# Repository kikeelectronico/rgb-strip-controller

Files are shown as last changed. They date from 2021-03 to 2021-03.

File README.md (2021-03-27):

View this project on [CADLAB.io](https://cadlab.io/project/24089). 

# RGB Strip controller


***

<br /><span xmlns:dct="http://purl.org/dc/terms/" property="dct:title">RGB strip controller</span> by <span xmlns:cc="http://creativecommons.org/ns#" property="cc:attributionName">Enrique Gómez</span> licensed by <a rel="license" href="http://creativecommons.org/licenses/by-sa/4.0/">Creative Commons Attribution-ShareAlike 4.0 International License</a>.<br /><br />

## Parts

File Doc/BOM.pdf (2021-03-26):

## RGB strip - Rev. 1,0 - Mouser

## Página 1

# RGB strip – Bill of Materials

Rev.: 1,0 | Made By: Enrique Gómez | Verify By: | Date: 03/09/19
Item Designator | Description | Ordering code | Suplier | Manufacturer | Footprint Qty. | Ordering code 2 | Suplier 2 | Value
1 | Q1,Q2,Q3,Q4 | N-channel MOSFET 771-PMV20XNEAR | Mouser | Nexperia | SOT-23 | 4 | PMV20XNEAR | Nexperia
2 | U1 | Linear regulator | 863-MC33275DT-3.3RKG | Mouser | ON Semicon | TO-252-2 | 1 | MC33275DT-3.3RKG | ON Semicon
3 | J1 | Power Jack | 992-CON-SOCJ-2155 | Mouser | Gravitech | 5,5/2,1 mm | 1 | CON-SOCJ-2155 | Gravitech
4 | C1,C2 | | 791-0603X334K250CT | Mouser | Walsin Tech Corp | 0603 | 2 | 0603X334K250CT
5 | R1,R2,R3 | Resistor 10k | 667-ERJ-PB3B1002V | Mouser | Panasonic | 0603 | 1 | ERJPB3B1002V | Panasonic
6 | SW1 | Push button | 688-SKQYAF | Mouser | ALPS | 6,10/3,7 mm | 1 | SKQYAFE010 | ALPS
7 | D2 | Bicolor led | 604-APHB1608QBDCGKC | Mouser | Kingbright | 0603 | 1 | APHB1608QBDCGKC | Kingbright
8 | R5 | Resistor 15 ohm | 667-ERJ-3GEYJ150V | Mouser | Panasonic | 603 | 1 | ERJ-3GEYJ150V | Panasonic
9 | R4 | Resistor 60,4 ohm 667-ERJ-3EKF60R4V | Mouser | Panasonic | 0603 | 1 | ERJ-3EKF60R4V | Panasonic
10 | U2 | ESP8266 | C82891 | LCSC | Ai-Thinker | Module | 1 | ESP-12F(ESP8266MOD) Ai-Thinker
11 | J2 | Header strip | | | | 01x04
12

### Notas:

Multilayer ceramic
capacitor

Walsin Tech
Corp

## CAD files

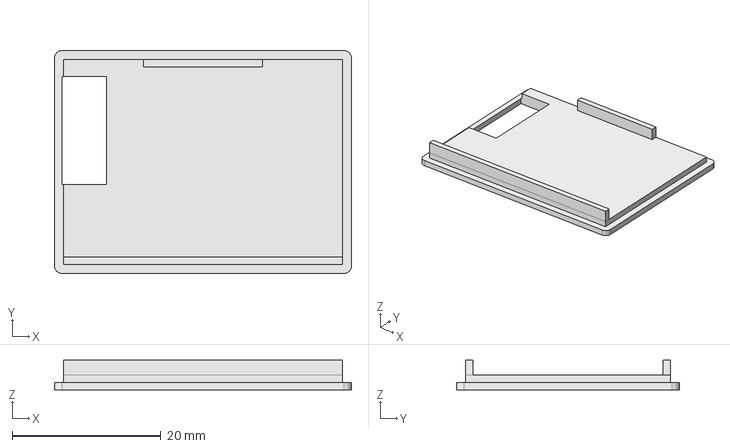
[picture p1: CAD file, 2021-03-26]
enclosure/cover.FCStd
40.0 x 30.0 x 4.00 mm

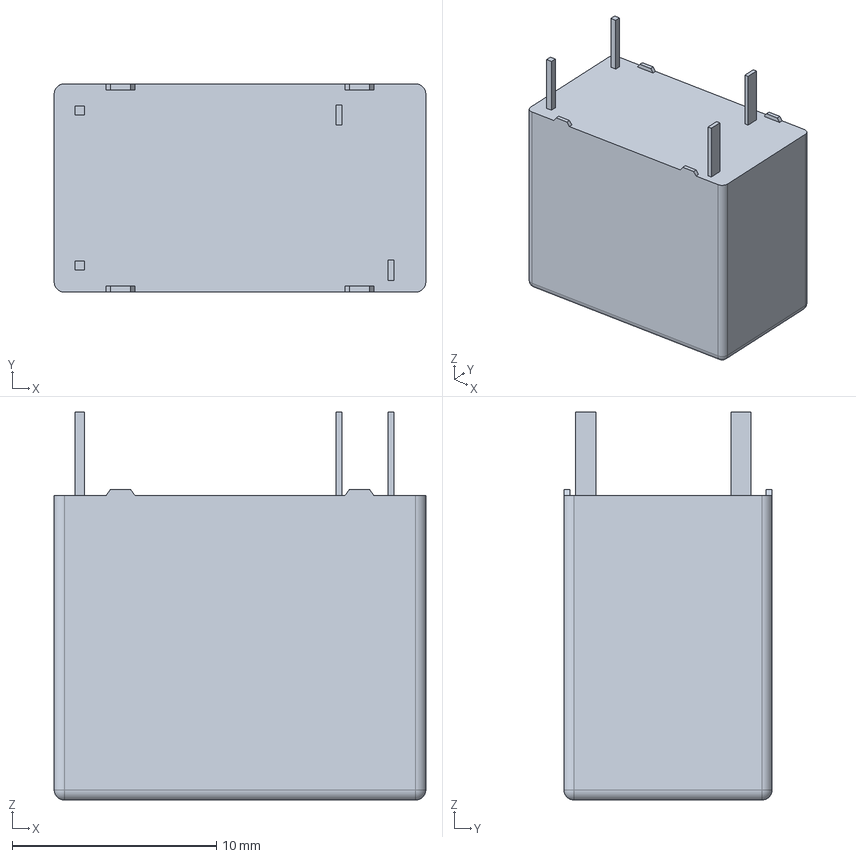
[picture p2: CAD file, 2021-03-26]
Kicad/RGB_strip/3dpackages/c-1461492-2-d4-3d.stp
18.2 x 10.2 x 19.0 mm

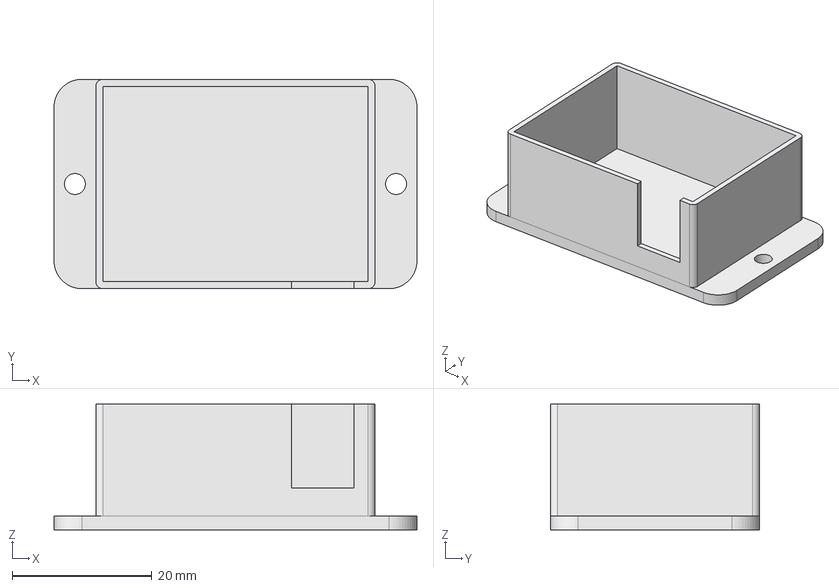
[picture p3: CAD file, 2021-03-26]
enclosure/box.FCStd
52.0 x 30.0 x 18.0 mm

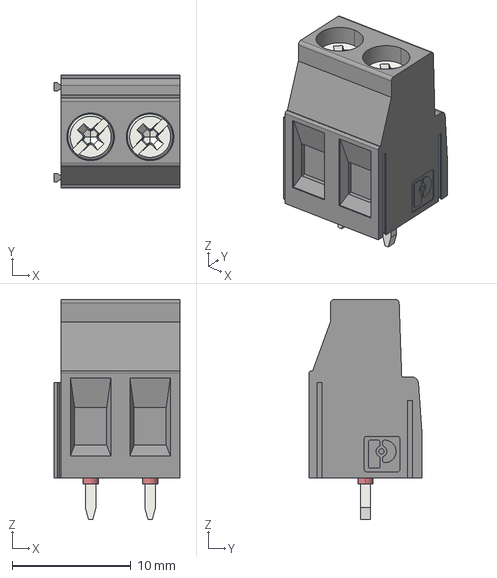
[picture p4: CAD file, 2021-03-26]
Kicad/RGB_strip/3dpackages/pxc_1985920_00_MKDSN-2-5-2-HT-BK_3D.stp
10.6 x 9.50 x 18.5 mm
Bohrloch x 2
mkdsn_2.5-2-ht_bk

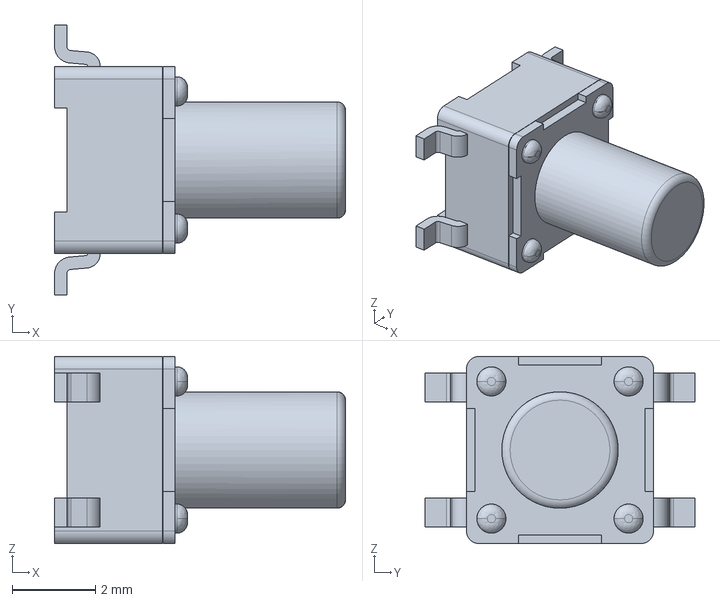
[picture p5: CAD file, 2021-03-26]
Kicad/RGB_strip/3dpackages/PTS647SN70SMTR2LFS.stp
7.00 x 6.50 x 4.50 mm

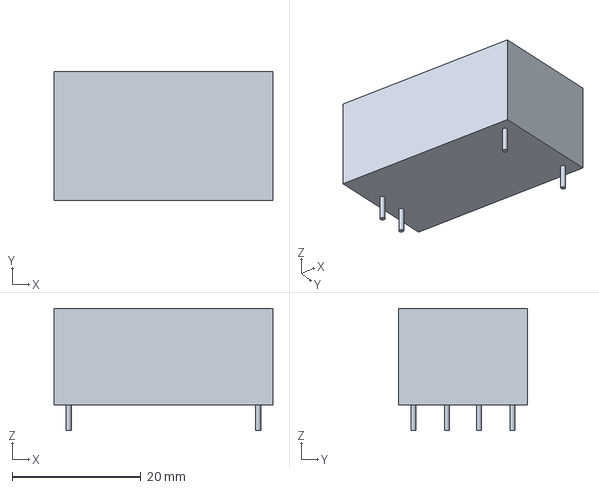
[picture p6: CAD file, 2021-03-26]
Kicad/RGB_strip/3dpackages/AC-DC_HLK-PM01.fcstd
34.0 x 20.0 x 19.0 mm

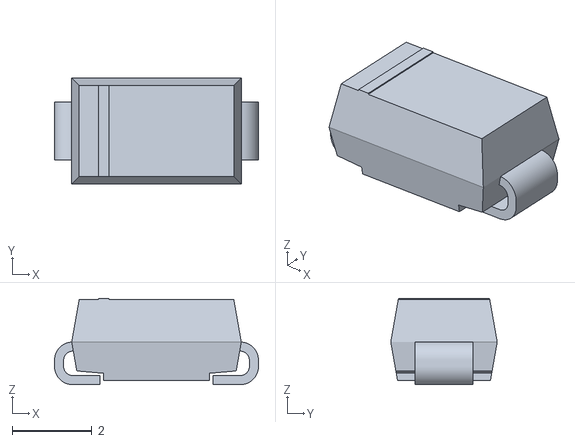
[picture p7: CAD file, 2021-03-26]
Kicad/RGB_strip/3dpackages/AB2_DO-214AC_WINGS3D.stl
5.11 x 2.66 x 2.16

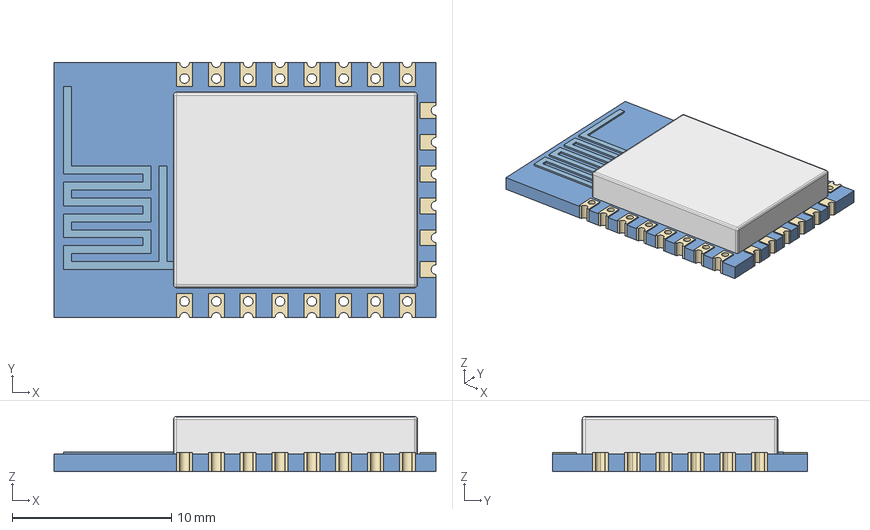
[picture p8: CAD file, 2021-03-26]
Kicad/RGB_strip/3dpackages/ESP8266.fcstd
24.0 x 16.0 x 3.48 mm

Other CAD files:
Kicad/RGB_strip/3dpackages/ESP8266-12E.stp
enclosure/box.stl
enclosure/cover.stl

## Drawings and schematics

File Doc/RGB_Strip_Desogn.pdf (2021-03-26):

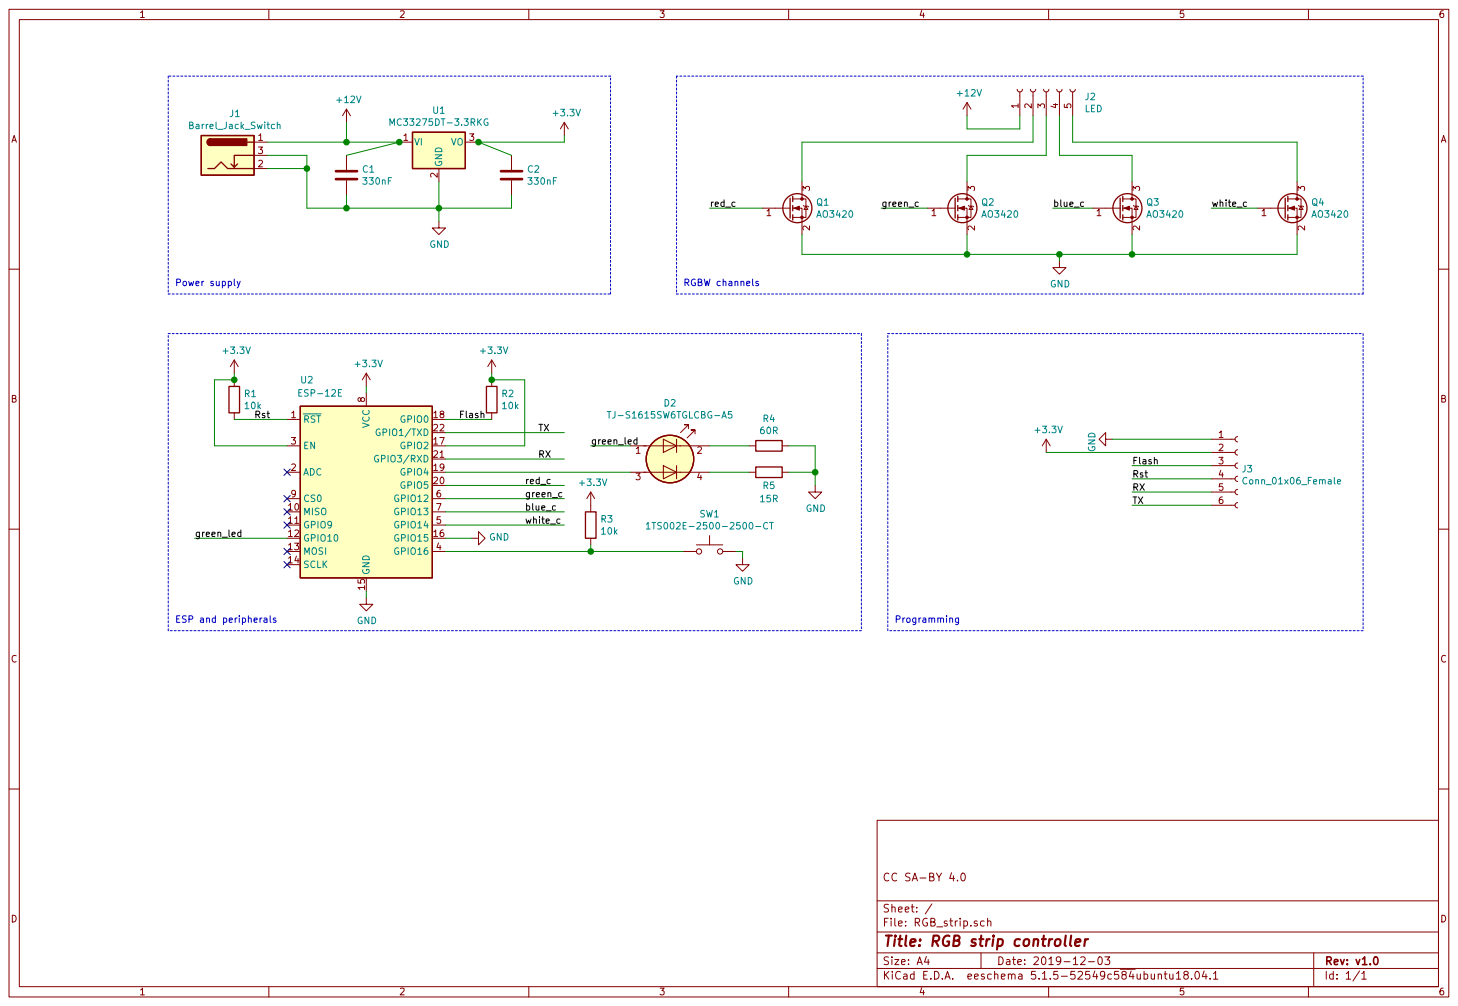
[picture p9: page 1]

2 3 Q4AO3420 RST 1 MISO 10 GPIO9 11 GPIO10 12 MOSI 13 SCLK 14 GND 15 GPIO15 16 GPIO2 17 GPIO0 18 GPIO4 19 ADC 2 GPIO5 20 GPIO3/RXD 21 GPIO1/TXD 22 EN 3 GPIO16 4 GPIO14 5 GPIO12 6 GPIO13 7 VCC

File: RGB_strip.sch Sheet: / CC SA-BY 4.0 R3

Id: 1/1 Title: RGB strip controller

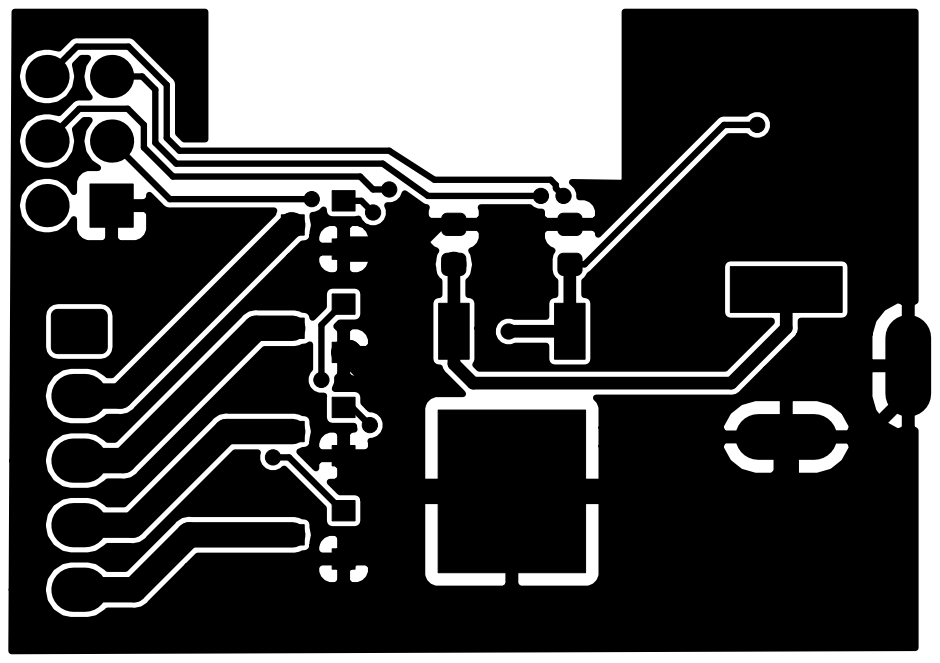
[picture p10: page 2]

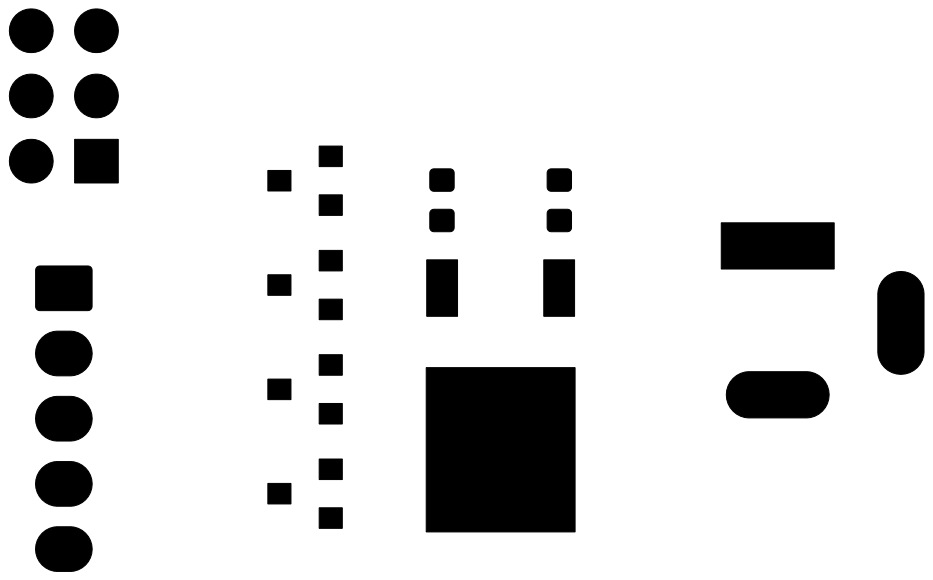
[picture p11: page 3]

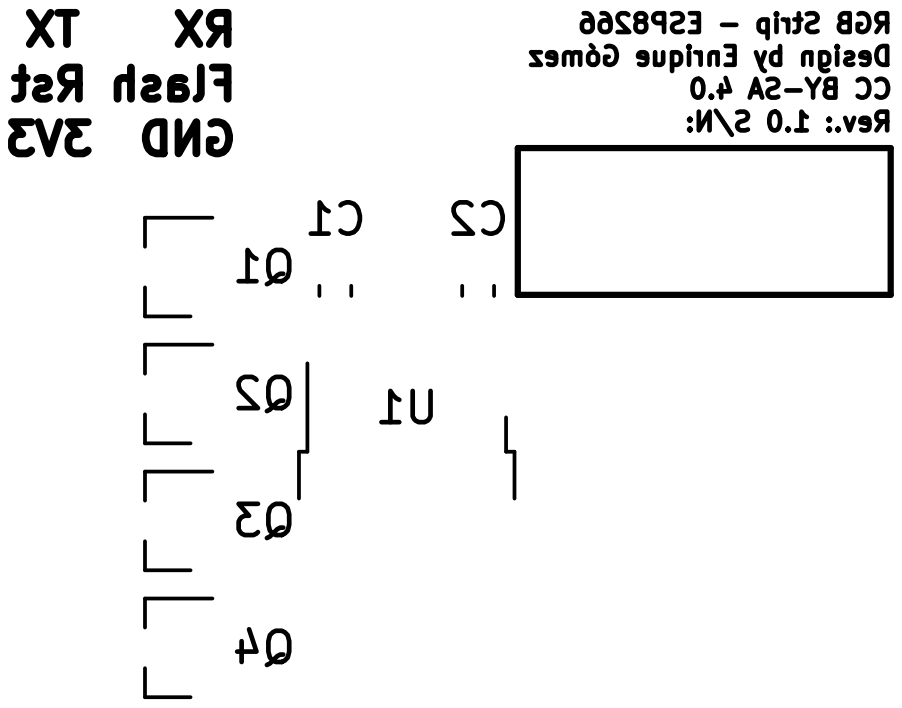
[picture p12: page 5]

RGB Strip - ESP8266 Design by Enrique Gómez CC BY-SA 4.0 Rev.: 1.0 S/N: RX TX

Flash Rst GND 3V3 C1 C2 Q1 Q2 Q3 Q4 U1

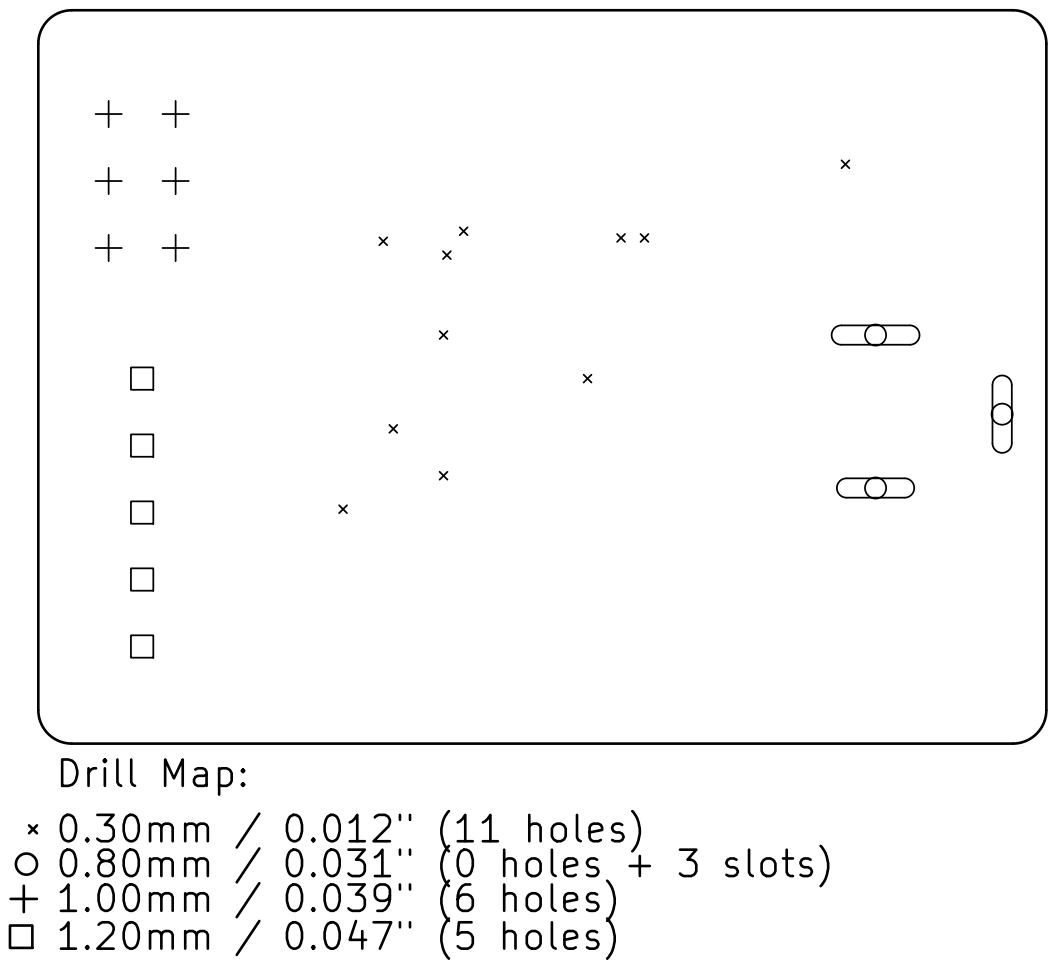
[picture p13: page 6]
Drill Map: 0.30mm / 0.012" (11 holes) 0.80mm / 0.031" (0 holes + 3 slots) 1.00mm / 0.039" (6 holes) 1.20mm / 0.047" (5 holes)

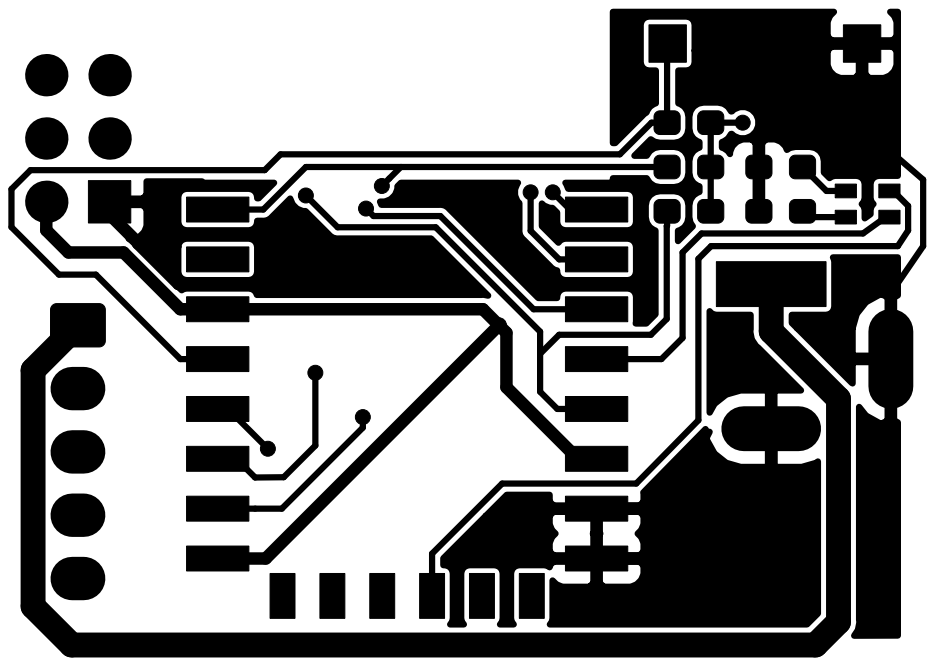
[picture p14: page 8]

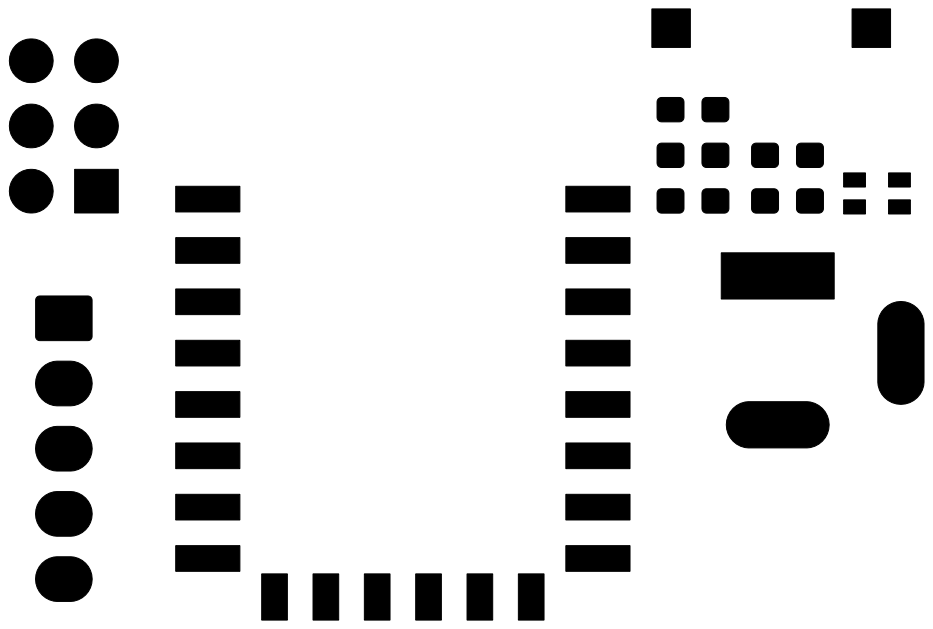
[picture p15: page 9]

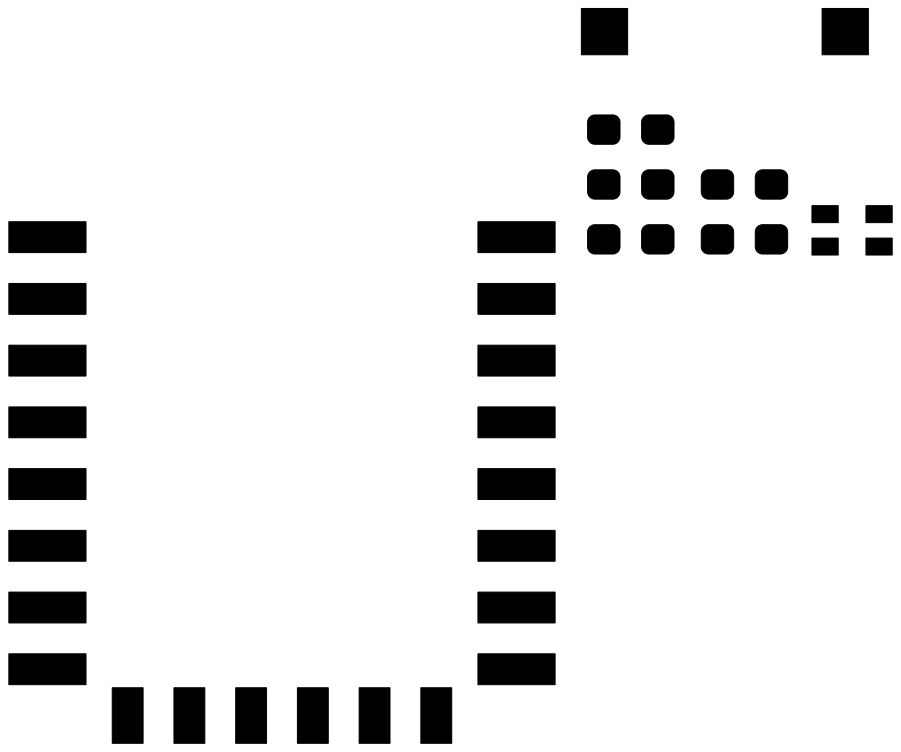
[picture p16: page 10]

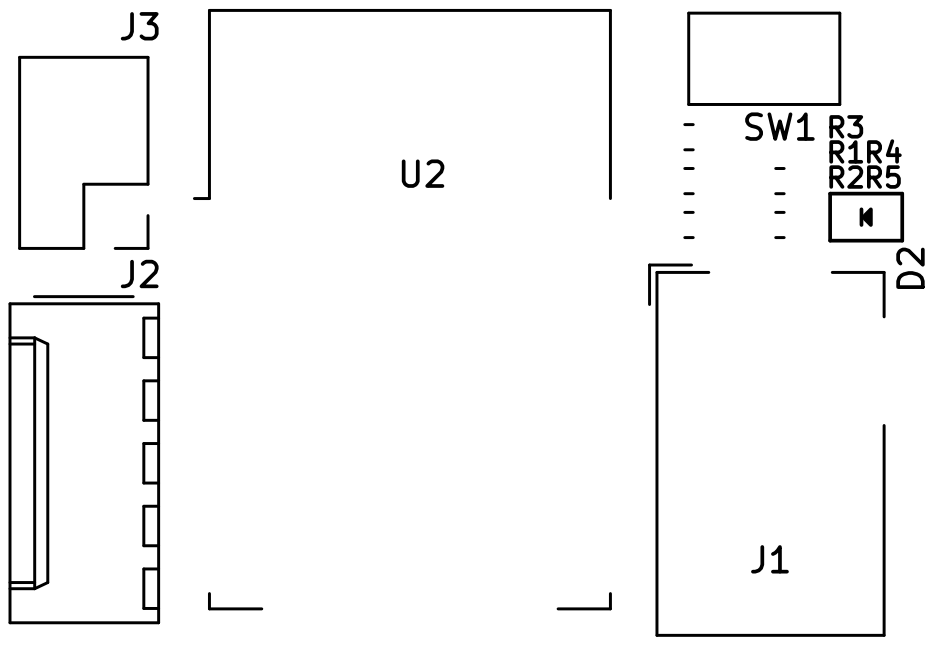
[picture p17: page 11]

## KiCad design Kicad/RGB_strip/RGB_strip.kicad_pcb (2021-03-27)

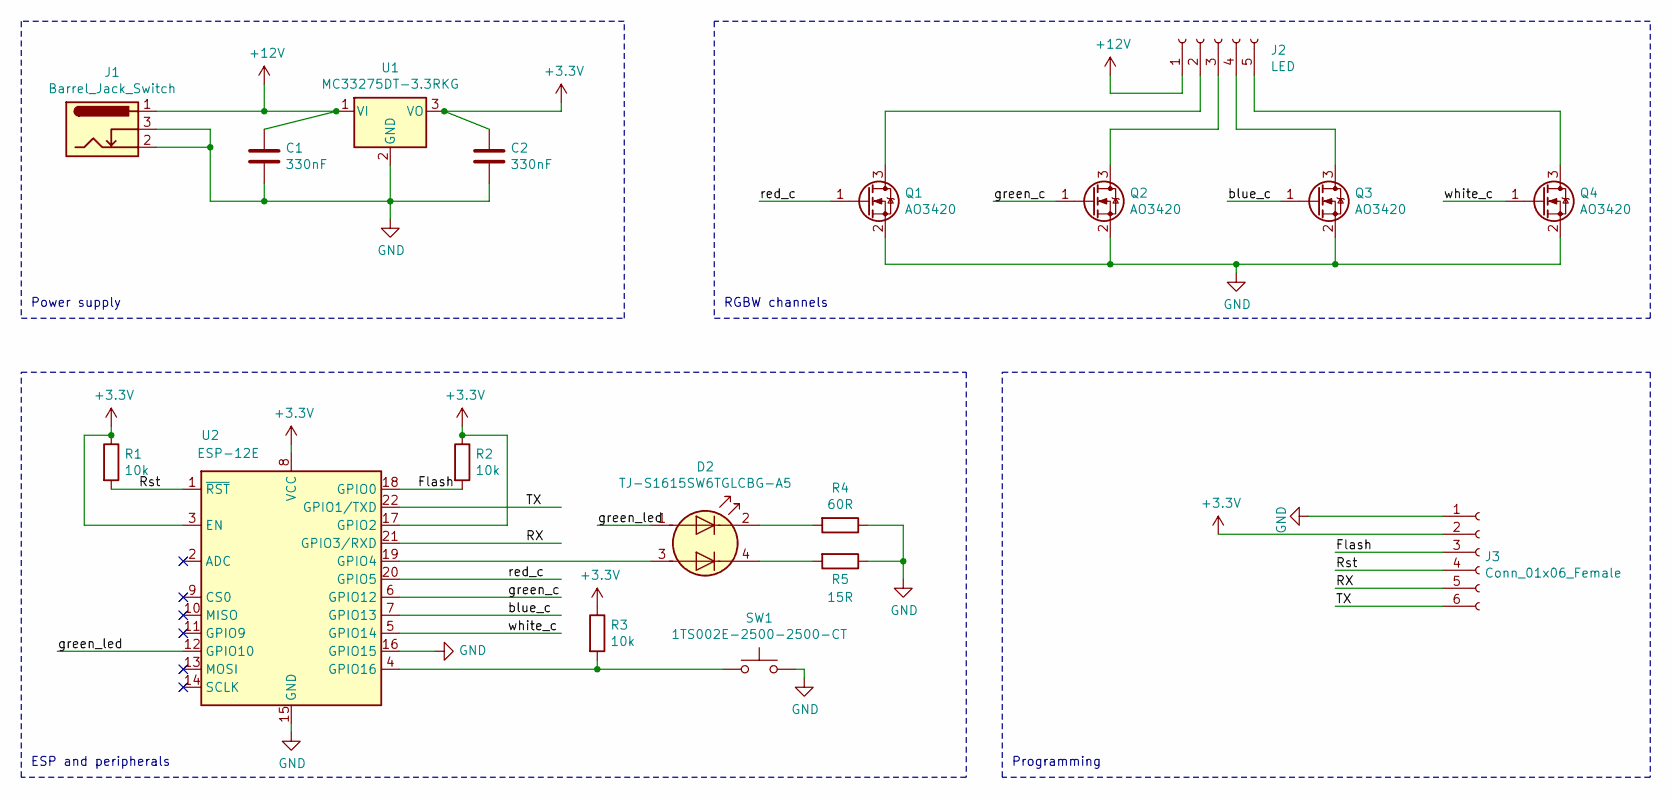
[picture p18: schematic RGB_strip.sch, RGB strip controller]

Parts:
C1, C2: 330nF; C_0603_1608Metric
D2: TJ-S1615SW6TGLCBG-A5
J1: Barrel_Jack_Switch; BarrelJack_Wuerth_6941xx301002
J2: LED; Molex_KK-254_AE-6410-05A_1x05_P2.54mm_Vertical
J3: Conn_01x06_Female; Molex_KK-254_AE-6410-06A_1x06_P2.54mm_Vertical
Q1, Q2, Q3, Q4: AO3420; SOT-23
R1, R2, R3: 10k; R_0603_1608Metric_Pad1.05x0.95mm_HandSolder
R4: 60R; R_0603_1608Metric_Pad1.05x0.95mm_HandSolder
R5: 15R; R_0603_1608Metric_Pad1.05x0.95mm_HandSolder
SW1: 1TS002E-2500-2500-CT; SW_SPST_CK_RS282G05A3
U1: MC33275DT-3.3RKG; TO-252-2
U2: ESP-12E

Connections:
+3V3: C2.1, J3.2, R1.1, R2.1, R3.1, U1.3 (VO), U2.3 (EN), U2.8 (VCC), U2.17 (GPIO2)
+12V: C1.1, J1.1, J2.1, U1.1 (VI)
/Flash: J3.3, R2.2, U2.18 (GPIO0)
/RX: J3.5, U2.21 (GPIO3/RXD)
/Rst: J3.4, R1.2, U2.1 (~RST)
/TX: J3.6, U2.22 (GPIO1/TXD)
/blue_c: Q3.1 (G), U2.7 (GPIO13)
/green_c: Q2.1 (G), U2.6 (GPIO12)
/green_led: D2.1 (A1), U2.12 (GPIO10)
/red_c: Q1.1 (G), U2.20 (GPIO5)
/white_c: Q4.1 (G), U2.5 (GPIO14)
GND: C1.2, C2.2, J1.2, J1.3, J3.1, Q1.2 (S), Q2.2 (S), Q3.2 (S), Q4.2 (S), R4.1, R5.1, SW1.2, U1.2 (GND), U2.15 (GND), U2.16 (GPIO15)
unnamed: D2.2 (K1), R4.2
unnamed: D2.3 (A2), U2.19 (GPIO4)
unnamed: D2.4 (K2), R5.2
unnamed: J2.2, Q1.3 (D)
unnamed: J2.3, Q2.3 (D)
unnamed: J2.4, Q3.3 (D)
unnamed: J2.5, Q4.3 (D)
unnamed: R3.2, SW1.1, U2.4 (GPIO16)

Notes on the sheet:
Power supply
RGBW channels
ESP and peripherals
Programming

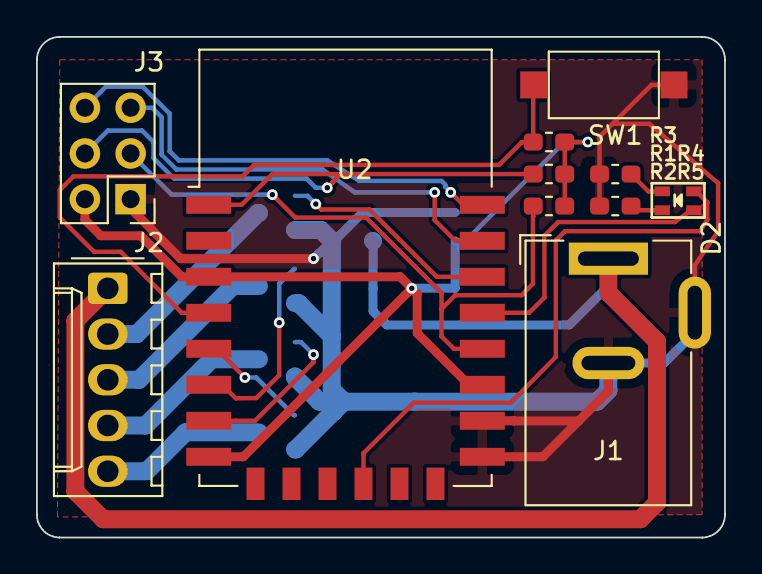
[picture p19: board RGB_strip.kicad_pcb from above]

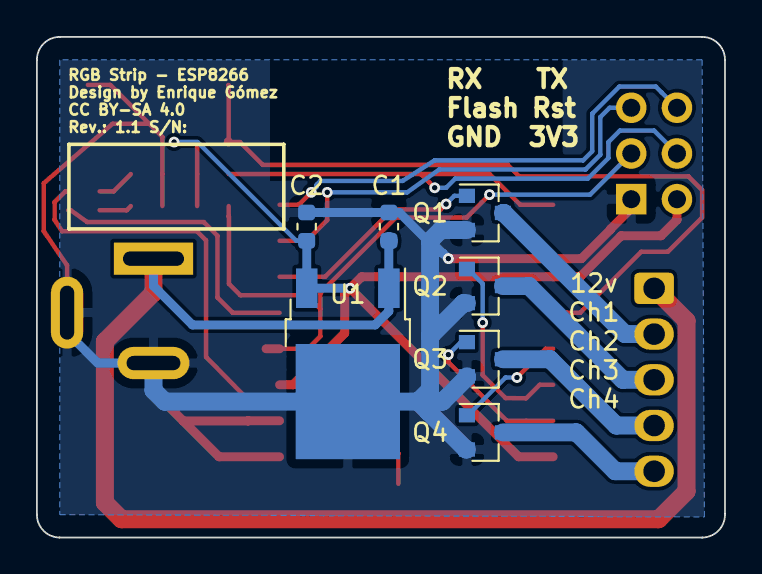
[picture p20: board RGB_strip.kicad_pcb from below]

Board: 2 copper layers, 38.2 x 27.8 mm, 18 parts (7 on the bottom side), 20 nets.

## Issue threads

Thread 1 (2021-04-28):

General questions

YSmetana, 2021-04-28:
Hello! :) I came across your project, and just wondering if you have got a chance to test the device in real life? Looking for something small like this for my home automation project. Is MC33275DT good enough with 12V input, how about heating? Also, can AO3420 be fully opened by GPIO out signal? Thank you!

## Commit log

2021-03-26 kick off
    [AB2_DO-214AC_WINGS3D.stl, AC-DC_HLK-PM01.fcstd, BOM.ods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]
2021-03-27 add labels
    [RGB_strip.kicad_pcb]
2021-03-27 update gerbers
    [RGB_strip-B.Cu.gbr, RGB_strip-B.Mask.gbr, RGB_strip-B.Paste.gbr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]
